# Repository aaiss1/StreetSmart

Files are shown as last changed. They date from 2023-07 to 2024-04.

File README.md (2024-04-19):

# StreetSmart

A bicycle safety device designed and built by 4 senior computer engineering students.

## Installing the Neopixel Library
```
sudo pip3 install rpi_ws281x adafruit-circuitpython-neopixel
sudo python3 -m pip install --force-reinstall adafruit-blinka
sudo apt-get install python-dev python3-dev -y
sudo pip3 install --upgrade RPi.GPIO
```

## Installing the RF24 Library
```
mkdir ~/rf24libs
cd ~/rf24libs
git clone https://github.com/TMRh20/RF24
cd ~/rf24libs/RF24
./configure
sudo make install
#Choose the SPIDEV Option
sudo apt-get install python3-dev libboost-python-dev
#Use ldconfig -p | grep libboost_python to find the number after libboost_python
sudo ln -s $(ls /usr/lib/arm-linux-gnueabihf/libboost_python3*.so | tail -1) /usr/lib/arm-linux-gnueabihf/libboost_python3.so
sudo apt-get install python3-setuptools
cd pyRF24/
sudo python3 setup.py build
sudo python3 setup.py install
sudo apt-get install python3-dev python3-rpi.gpio
```
## Connections for NRF24L01
```
On the Raspberry Side, the COMM Connections are
CSN_PIN = 0  # connected to GPIO8// ITS THE RASPI's CE PIN #
CE_PIN = 17  # connected to GPIO17
```

## File Hierarchy
- global_vars.py
    - main.py
        - lighting.py
        - comm.py     
        - accel.py    
        - lidar_dist.py          

## StreetSmart Service
### How to Run streetsmart on startup
```
sudo cp streetSmart.service /etc/systemd/system/
sudo systemctl daemon-reload
sudo systemctl enable streetSmart.service # Requires Reboot
#OR
sudo systemctl enable streetSmart.service --now #Runs as soon as called
```
### How to Stop streetsmart from running on startup
```
sudo systemctl disable streetSmart.service
```

### How to stop streetsmart when it is already running on startup
```
sudo systemctl stop streetSmart.service
```

## How to Run StreetSmart Manually

```
sudo python3 main.py

#CTRL C to kill
```

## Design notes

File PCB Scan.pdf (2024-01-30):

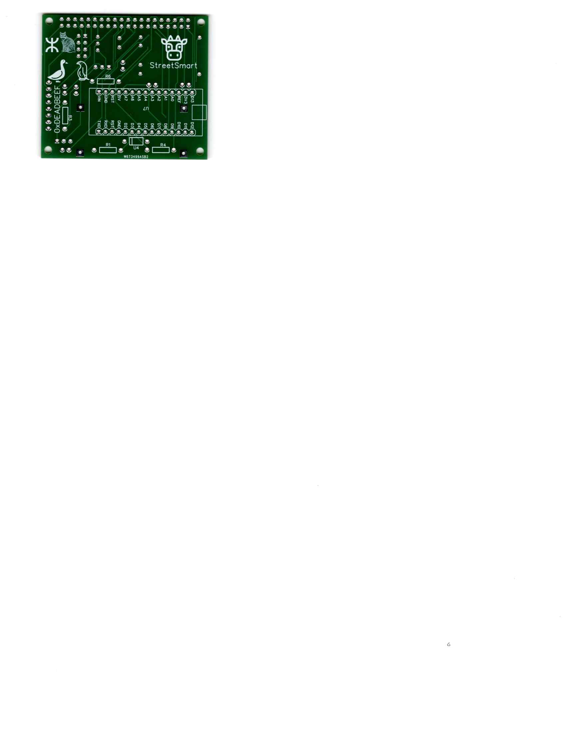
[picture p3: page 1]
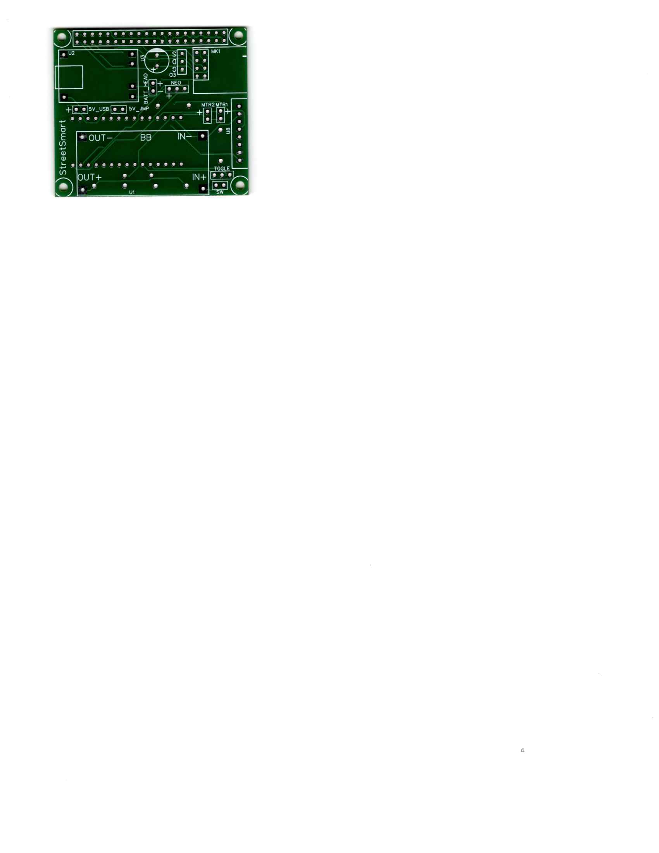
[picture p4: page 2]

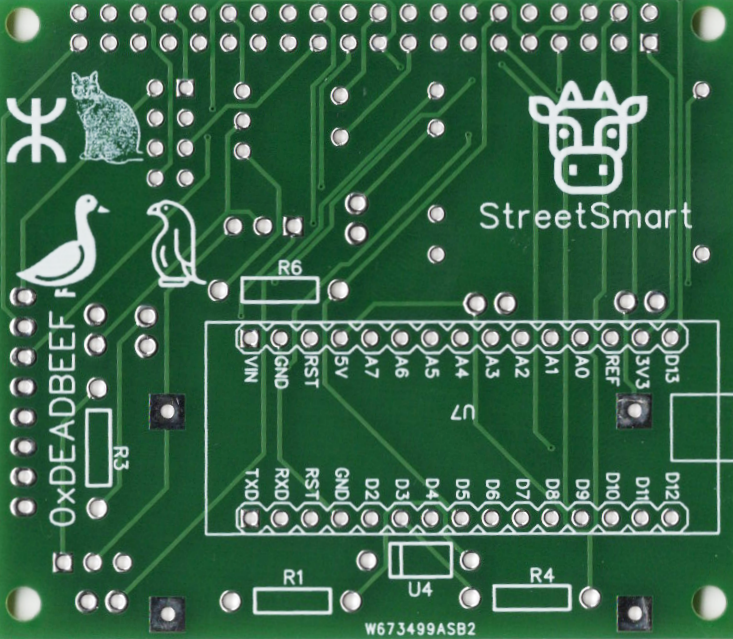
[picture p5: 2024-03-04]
PCB Scan _Cow.png

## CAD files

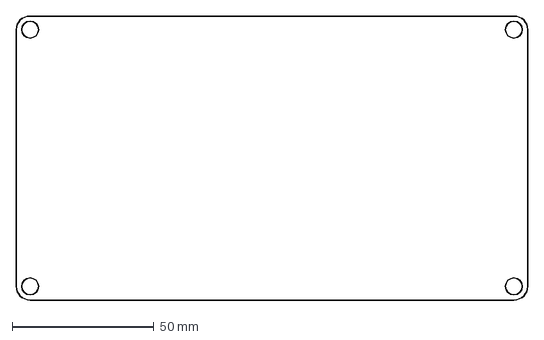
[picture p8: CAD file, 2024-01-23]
3D - Version 2/Acrylic Cover.dxf
180.0 x 100.0 mm

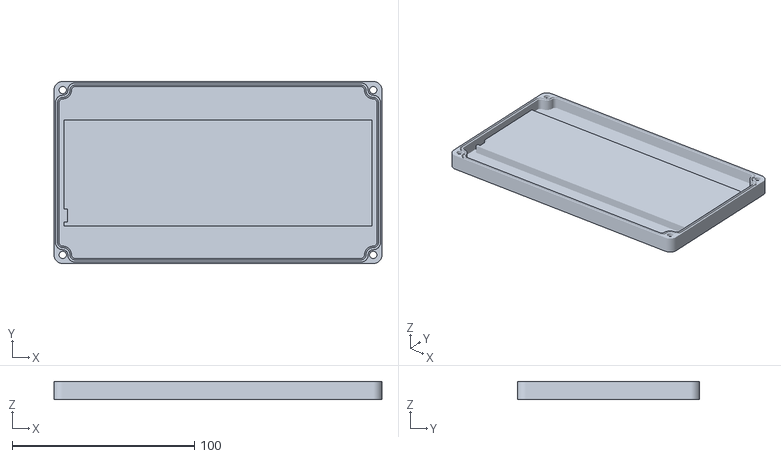
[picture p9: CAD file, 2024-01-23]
3D - Version 2/To Print 2024-01-21/Central-lid_2024_01_21.stl
180.0 x 100.0 x 10.0

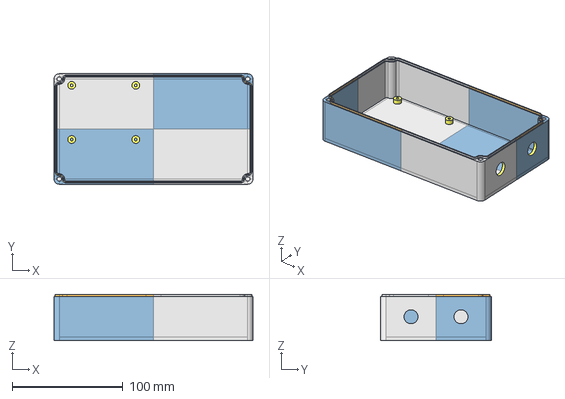
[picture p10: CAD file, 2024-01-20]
3D - Version 2/Central-base.step
180.0 x 100.0 x 41.7 mm

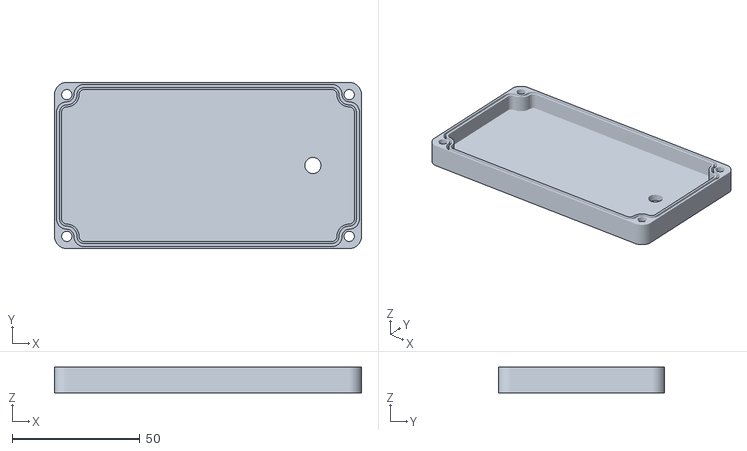
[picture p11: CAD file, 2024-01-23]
3D - Version 2/To Print 2024-01-21/Haptic Controller-lid v1.stl
120.0 x 65.0 x 10.0

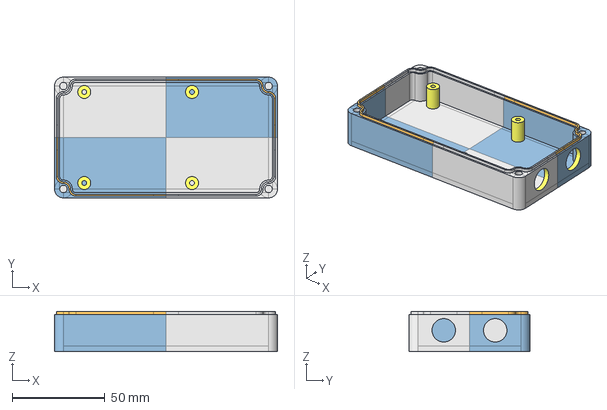
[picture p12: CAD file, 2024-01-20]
3D - Version 2/Haptic Controller-base.step
120.0 x 65.0 x 21.7 mm

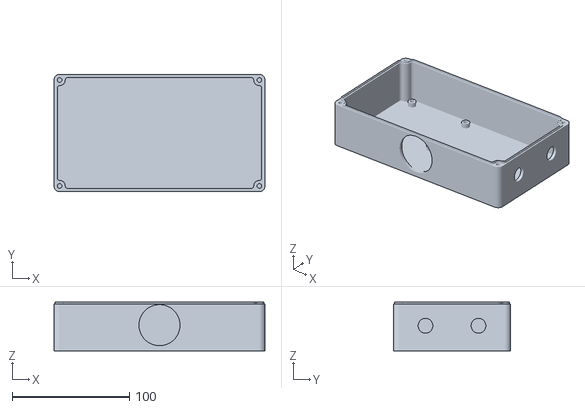
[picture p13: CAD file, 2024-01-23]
3D - Version 2/To Print 2024-01-21/Central-base v3.stl
180.0 x 100.0 x 41.7

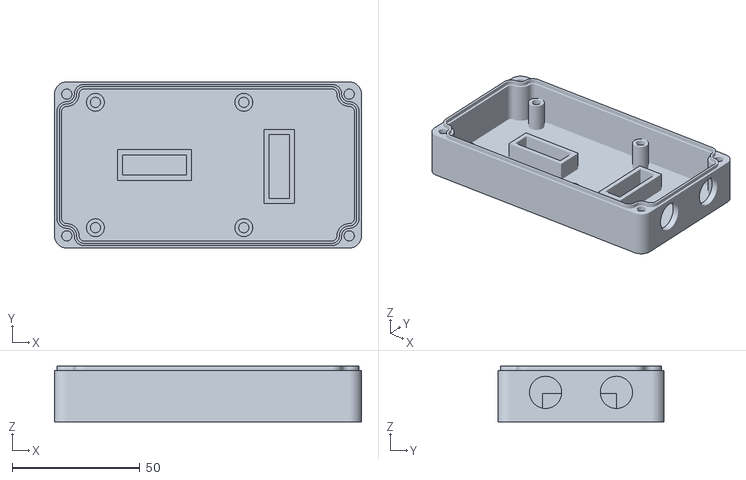
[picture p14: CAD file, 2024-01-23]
3D - Version 2/To Print 2024-01-21/Haptic Controller-base v2.stl
120.0 x 65.0 x 21.7

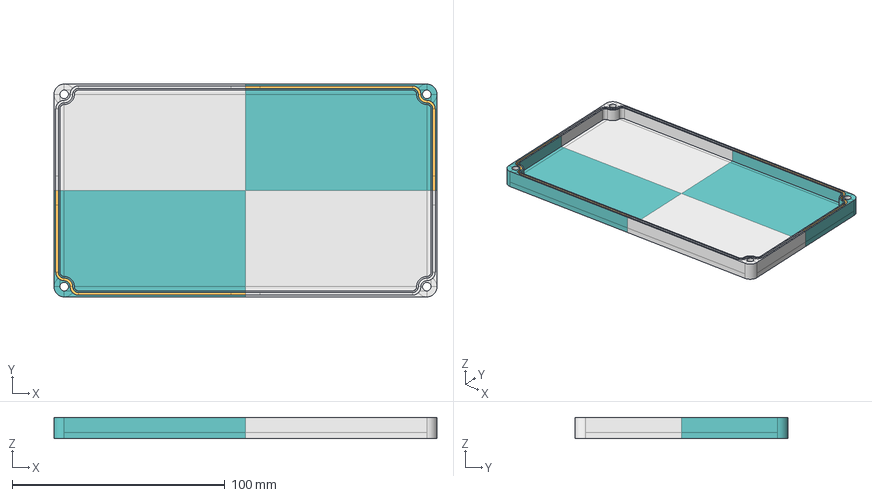
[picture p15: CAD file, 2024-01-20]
3D - Version 2/Central-lid.step
180.0 x 100.0 x 10.0 mm

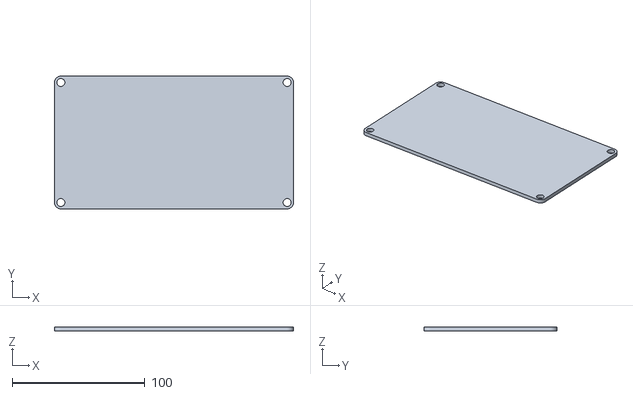
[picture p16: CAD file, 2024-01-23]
3D - Version 2/To Print 2024-01-21/clear_cover.stl
180.0 x 100.0 x 3.00

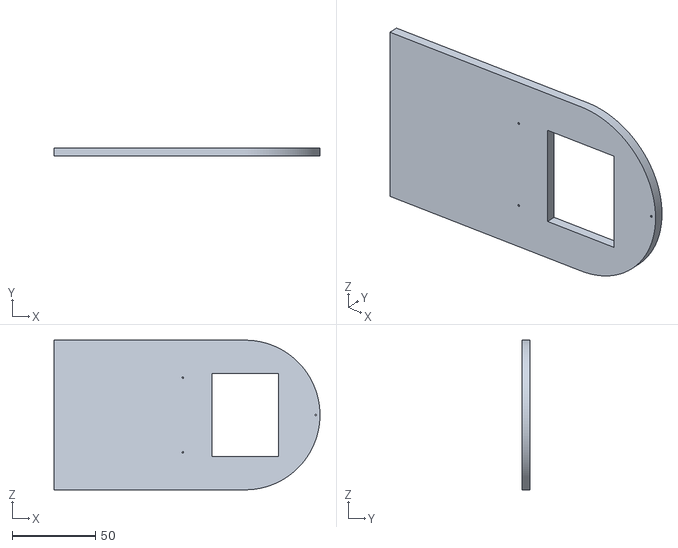
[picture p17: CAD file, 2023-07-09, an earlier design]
3D - Version 1/Central/right_front_plate.stl
160.0 x 5.00 x 90.0

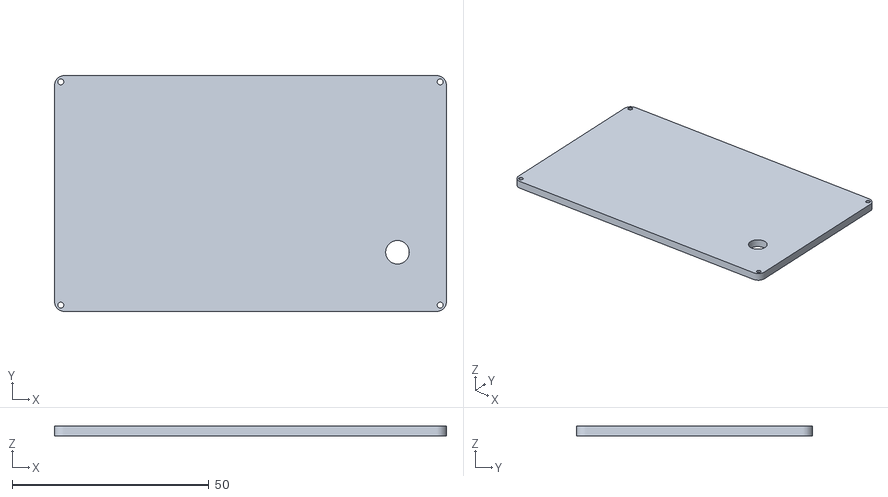
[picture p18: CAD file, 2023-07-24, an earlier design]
3D - Version 1/Haptic/wireless_lid2.stl
99.7 x 60.0 x 2.50

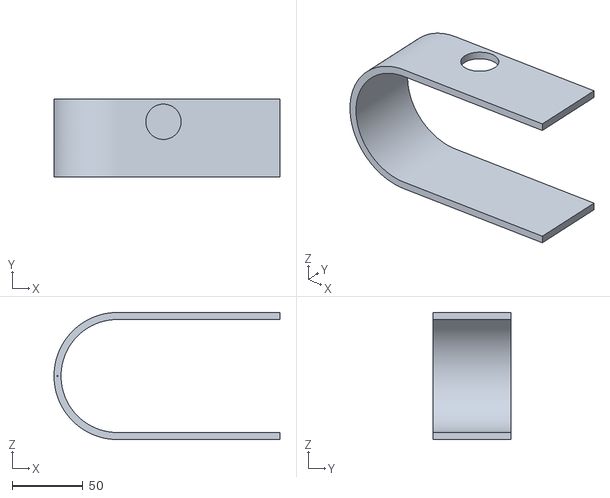
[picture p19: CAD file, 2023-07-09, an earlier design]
3D - Version 1/Central/left_body.stl
160.0 x 55.0 x 90.0

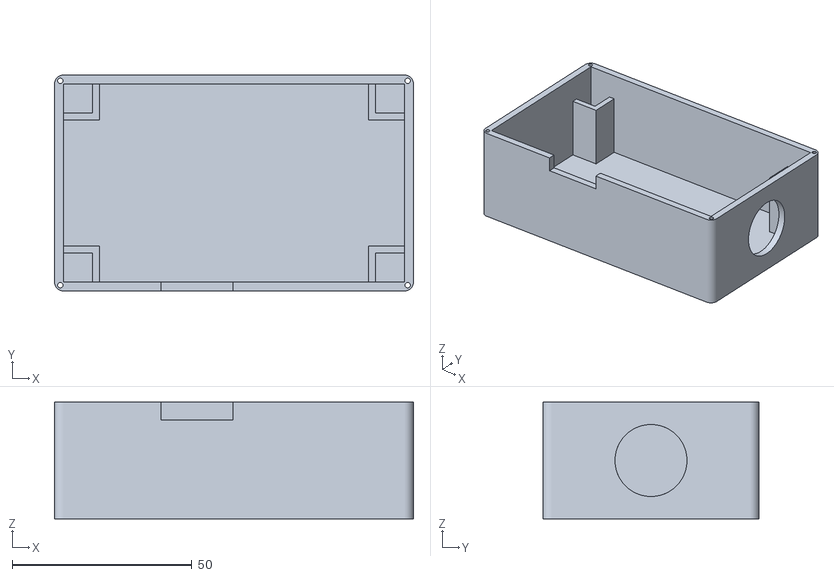
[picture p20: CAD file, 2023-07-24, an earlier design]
3D - Version 1/Haptic/wireless_container.stl
99.7 x 60.0 x 32.5

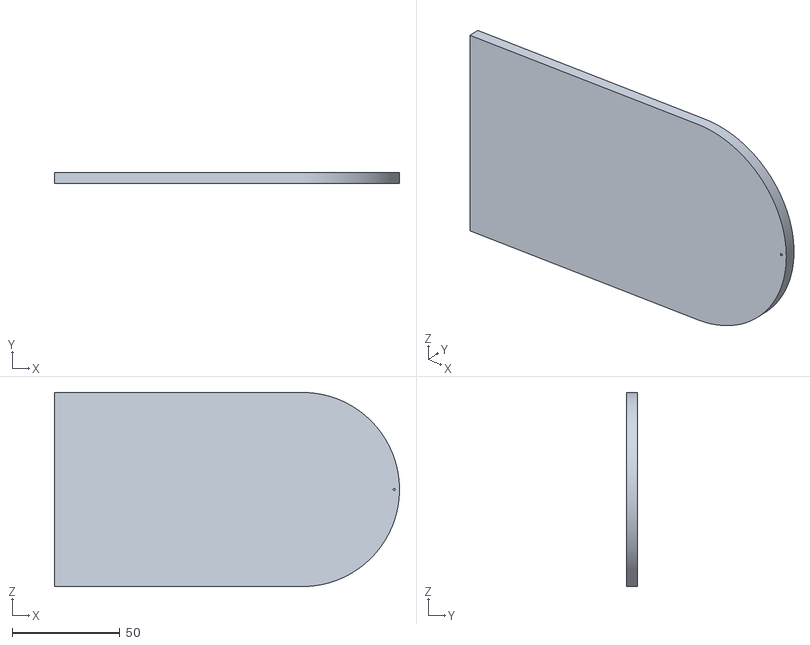
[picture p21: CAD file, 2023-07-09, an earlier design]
3D - Version 1/Central/right_back_plate.stl
160.0 x 5.00 x 90.0

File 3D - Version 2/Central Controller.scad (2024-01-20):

/*******************************************************************************
TITLE:
Stable and waterproof OpenSCAD case by pbtec

DESCRIPTION:

highly scalable case for 3D printing. Try it out!

Optimized for Openscad Customizer. Activate it under view/customizer and play around ;-)

No Support needed to print

- for waterproof cases you can use silicone sealing cord with diameters from 1 to 3mm
- to use also without sealing cord. The groove and ridge gives the housing a high stability and tightness.
- Use of regular nuts or square nuts
- define outer vertical radius of corners
- echo output in console shows inner and outer size and more
- echo output shows the needed length of the screws
- use screws from m2 up to m5
- default are 4 screws at each corner. For large cases add addtional ones in the middle of both x and y sides if needed
- use several predefined wall mount holder, some with multiple mounting holes (up to 3)

Important!
- If you use standard nuts you need to pause the printer a certain level to insert the nuts
- If you need a stable and waterproof case please print with 100% infill
- I'm aware that sometimes, when using too big or too small parameters, there are some rendering issues.
  To prevent such issues change only one parameter at once and check the result.

for waterproofness see https://blog.prusaprinters.org/watertight-3d-printing-part-2_53638/

AUTHOR:
pbtec / pb-tec.ch

use https://paypal.me/pbtec if you want to spend me a coold beer. Thanks in advance :-)


VERSION:
V   KZZ DATE     COMMENT
6.0 pb  31.07.21 First Version to share

*******************************************************************************/

/* [View settings] */
// Shows the Bottom of the case
ShowBottom                = true;
// Shows the top of the case
ShowTop                   = true;
// Distance between top and bottom (if both are side by side displayed)
DistanceBetweenObjects    = 10;
// Shows the housing assembled
ShowCaseAssembled         = false;


/* [Control cuts (use only one at a time)] */

// To see the nuts inside (best view if not assembled showed)
SeeNutCut                 = false;
// To see the groove, ridge and Screw (best view if assembled showed)
SeeGrooveRidgeScrew       = false;


/* [Case settings] */

// Length of the case
Caselength                = 60;
// Width of the case
CaseWidth                 = 80;
// Height of the case
CaseHeight                = 40;
// Splitt the Case height into bottom and top, check for the needed screws in echo output (console)
CutFromTop                = 10.0;    
// Thickness for the bottom and top wall (vertical walls needs to be calculated)
BottomTopThickness        = 3.0; 
// If this is bigger than the needed cylinder around the screw it will be ignored
CaseRadius                = 12.0;     

/* [Case Screw settings] */

//2=m2/2.5=m2.5/3=m3/4=m4/5=m5   // max m5, larger sizes do not fit
CountersinkScrew          = 3.0;     // [2:m2, 2.5: m2.5, 3: m3, 4: m4, 5: m5]

// Adds additional Screws on X axis (for large cases) --> Try it out
XAdditionalScrew          = false;  // can be true or false / Adds additional Screws on X axis (for large cases) --> Try it out
// Adds additional Screws on Y axis (for large cases) --> Try it out
YAdditionalScrew          = false;  // can be true or false / Adds additional Screws on Y axis (for large cases) --> Try it out

/* [Groove settings] */

// If using a SealingCord use the SealingCord diameter, otherwise x-times of your 3D Printer Nozzle (0.8/1.2/...) --> Ridge gets perfect for printing
GrooveWidth               = 1.2;   // [0.8:0.1:3]

// Not less than 1mm (for stability) and not more than 3mm --> Best 2mm
GrooveDepth               = 2.0;   // [1.0:0.1:3]

// Space between Groove and Ridge for a perfect fit, usualy 0.2 or 0.3 for FDM depending on your printer quality
Space                     = 0.3;   // [0.0:0.1:0.4]

// Addtional vertical room for the pressed sealing Cord. For sealing cord 1.5mm -->0.5 // for 2mm -->0.8 // for 2.5 -->1.0 // If no sealing cord then set this parameter to 0.
AddGrooveDepthForSealing  = 0.8;   // [0.0:0.1:3]   

// Range Inside groove/ridge. Usualy 2 times or more the printer nozzle. For best stability at least 0.8
InnerBorder               = 0.8;   // [0.8:0.1:4]


// Range Outside groove/ridge . Usualy 2 times or more the printer nozzle. For best stability at least 0.8
OuterBorder               = 0.8;   // [0.8:0.1:4]

/* [Nut general settings] */

// Size of material (plastic) above nut/square nut (3mm or more). The more, the more stable but need longer screw.
NutSink                   = 4.0; 

/* [Standard nut settings] */

// Nut Settings / As there are (or I have) many different nuts dimensions, the size must be specified / Do not add separation space, only the real measurement // m2=1.5 // m2.5=1.9 // m3=2.4 // m4=3.2 // n5=3.8
NutHigh                   = 2.4;   

// Distance between the paralell sides / Do not add separation space, only the real measurement // m2=3.8 // m2.5=4.9 // m3=5.4 // m4=6.9 // m5=7.9
NutDia                    = 5.4;   

/* [Square Nut settings] */

// Select if you want to use square nuts instead of normal nuts
UseSquareNutInsteadOfNut  = false; 

// Select the high of the square nut / Do not add separation space, only the real measurement
SquareNutHigh             = 1.9;

// Select the size of the square nut / Do not add separation space, only the real measurement
SquareNutSize             = 5.4;

// Square nut insert from which side
EdgeSquareNutInsertFrom_X = true;       

/* [Wall mount holder settings] */
 
// Select if you need a mount holder
EnableMountHolder         = false; 

// Chose your desired wall mount style
MountHolderStyle          = 5;      // [1:Style 1, 2: Style 2, 3: Style 3, 4 : Style 4, 5 : Style 5]

// Some styles (1-3) allow more than one hole
CountOfMountHolderHoles   = 1;     // [1:One hole centered, 2: Two holes, 3: Three holes]
MountHolderHoleDiameter   = 5;   // [1:0.1:10]
MountHolderThickness      = 4.0;   // [2:0.1:10]

/* [PCB/Device holder settings] */
// Activate customizable PCB/Device holder
ShowDeviceHolder         = false;
// Hole in the cylinder for the screw // 2.9 Screw = 2mm hole
ScrewHoleDiameter        = 2.6;  
// The diamter of the screw cylinder
ScrewCylinderDiameter    = 7;
// The height of the screw cylinders (also the deepness for the screw hole)
ScrewCylinderHeight      = 8.0;
// Distance between the holders in X direction
DeviceHolder_X_Distance  = 60;
// Distance between the holders in Y direction
DeviceHolder_y_Distance  = 80;
// Move all holders in X direction
Offset_X                 = 0;
// Move all holders in Y direction
Offset_Y                 = -20;

/* [Wall Holes settings (for cable gland cut)] */
// Activate customizable holes for cable gland or similar
ShowSideWallHoles        = false;
// Holes on X or Y side of the housing
SideWallHolesOn_X        = false;
// Count of holes, if there is an additional screw on X or Y side the hole in the middle is not showed
CountOfSideWallHoles     = 1;     //[1:1:3]
// Diameter of the holes
SideWallHoleDiameter     = 16.5;  //[1:0.1:80]
// Add or decrease height position
SiedWallHoleOffset_Z     = 0;     



/* [Render quality settings] */
// Set to at least to 150 before render and save as .stl file, otherwise you can go down to 40 for quick 3D view
$fn                       = 60;   // [20:1:300] 

// =========================  C A L C U L A T E D   S E T T I N G S (do not change!!!) ===================================

// Calculated Screw settings (do not change!!!)
ScrewHoleDia              = CountersinkScrew+1;
ScrewHeadDia              = CountersinkScrew*2;
ScrewCountersink          = (CountersinkScrew+8)/14-0.5;

// Calculated settings for Ridge (do not change!!!)
RidgeHeight               = GrooveDepth-Space;
RidgeWidth                = GrooveWidth-Space;

// Calculated settings for case (do not change!!!)
SideWallThickness             = InnerBorder+GrooveWidth+OuterBorder;
CaseRoundingRadius        = ScrewHoleDia/2+InnerBorder+GrooveWidth+OuterBorder;
ScrewCornerPos            = [Caselength/2-CaseRoundingRadius,CaseWidth/2-CaseRoundingRadius,0];
ScrewAddXPos              = [0,CaseWidth/2-CaseRoundingRadius,0];
ScrewAddYPos              = [Caselength/2-CaseRoundingRadius,0,0];

// Calculated settings for wall mount holder
MountHolderLenght         = MountHolderHoleDiameter*3;

// if both objects showed
X_ObjectPosition = ((ShowBottom)&&(ShowTop)&&(!ShowCaseAssembled)) ? Caselength/2+DistanceBetweenObjects/2:0;

// If the case is assembled showed
Y_TopRotation = ShowCaseAssembled ? 180:0;
Z_TopHigh = ShowCaseAssembled ? CaseHeight:0;

ShowSizes(); // Show the calculated sizes

//===============================================================================
//                                    M A I N
//===============================================================================
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

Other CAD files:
3D - Version 2/Haptic Controller-lid.step
3D - Version 1/Central/left_back_plate.stl
3D - Version 1/Central/left_front_plate.stl
3D - Version 1/Central/right_body.stl
3D - Version 1/Central/light_panel.stl
3D - Version 2/Central-lid v5.f3d
3D - Version 2/Central-lid_v5_v1.f3d

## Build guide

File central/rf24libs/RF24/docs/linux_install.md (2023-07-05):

# Linux Installation

@tableofcontents

<!-- markdownlint-disable MD031 -->
Generic Linux devices are supported via SPIDEV, MRAA, RPi native via BCM2835, or using LittleWire.

@note The SPIDEV option should work with most Linux systems supporting spi userspace device.

@warning These install instructions are beginning to age because they were designed with the assumption that
the arm-linux-gnueabihf-g\*\* compilers were available and default for the system. If you have problems
using the manual install instructions (especially on a 64-bit OS), please try the
[instructions using CMake](md_docs_using_cmake.html).

@note Since wiringPi is no longer maintained or distributed (as of RPi OS 11 bullseye),
pigpio is now required for using the radio's IRQ pin. This applies to RPi, SPIDEV, and pigpio drivers. The MRAA driver may provide its own IRQ implementation. Remember that the RPi OS lite variant does not ship with pigpio installed.

## Automated Install

**Designed & Tested on RPi** - Defaults to SPIDEV on devices supporting it

1. Install prerequisites if there are any (pigpio, MRAA, LittleWire libraries, setup SPI device etc)
2. Download the install.sh file from [http://tmrh20.github.io/RF24Installer/RPi/install.sh](http://tmrh20.github.io/RF24Installer/RPi/install.sh)
   ```shell
   wget http://tmrh20.github.io/RF24Installer/RPi/install.sh
   ```
3. Make it executable
   ```shell
   chmod +x install.sh
   ```
4. Run it and choose your options
   ```shell
   ./install.sh
   ```
5. Run an example from one of the libraries
   ```shell
   cd rf24libs/RF24/examples_linux
   ```
   Edit the gettingstarted example, to set your pin configuration
   ```shell
   nano gettingstarted.cpp
   make
   sudo ./gettingstarted
   ```

## Manual Install

1. Install prerequisites if there are any (pigpio, MRAA, LittleWire libraries, setup SPI device etc)
   @note See the [MRAA](http://iotdk.intel.com/docs/master/mraa/index.html) documentation for more info on installing MRAA
2. Make a directory to contain the RF24 and possibly RF24Network lib and enter it
   ```shell
   mkdir ~/rf24libs
   cd ~/rf24libs
   ```
3. Clone the RF24 repo
   ```shell
   git clone https://github.com/tmrh20/RF24.git RF24
   ```
4. Change to the new RF24 directory
   ```shell
   cd RF24
   ```
5. Configure build environment using
   ```shell
   ./configure
   ```
   script. It auto detectes device and build environment.

   For overriding autodetections, use command-line switches, see
   ```shell
   ./configure --help
   ```
   for description.
6. Build the library, and run an example file
   ```shell
   make
   sudo make install
   ```
   ```shell
   cd examples_linux
   ```
   Edit the gettingstarted example, to set your pin configuration
   ```shell
   ano gettingstarted.cpp
   make
   sudo ./gettingstarted
   ```

### Build using SPIDEV

1. Make sure that spi device support is enabled and /dev/spidev\<a\>.\<b\> is present
2. Manual Install using SPIDEV:
   ```shell
   ./configure --driver=SPIDEV
   make
   sudo make install
   ```
3. See the gettingstarted example for an example of pin configuration

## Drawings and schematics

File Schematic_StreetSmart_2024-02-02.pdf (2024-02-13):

## Output is 5V for Central Output is 6V for Haptic

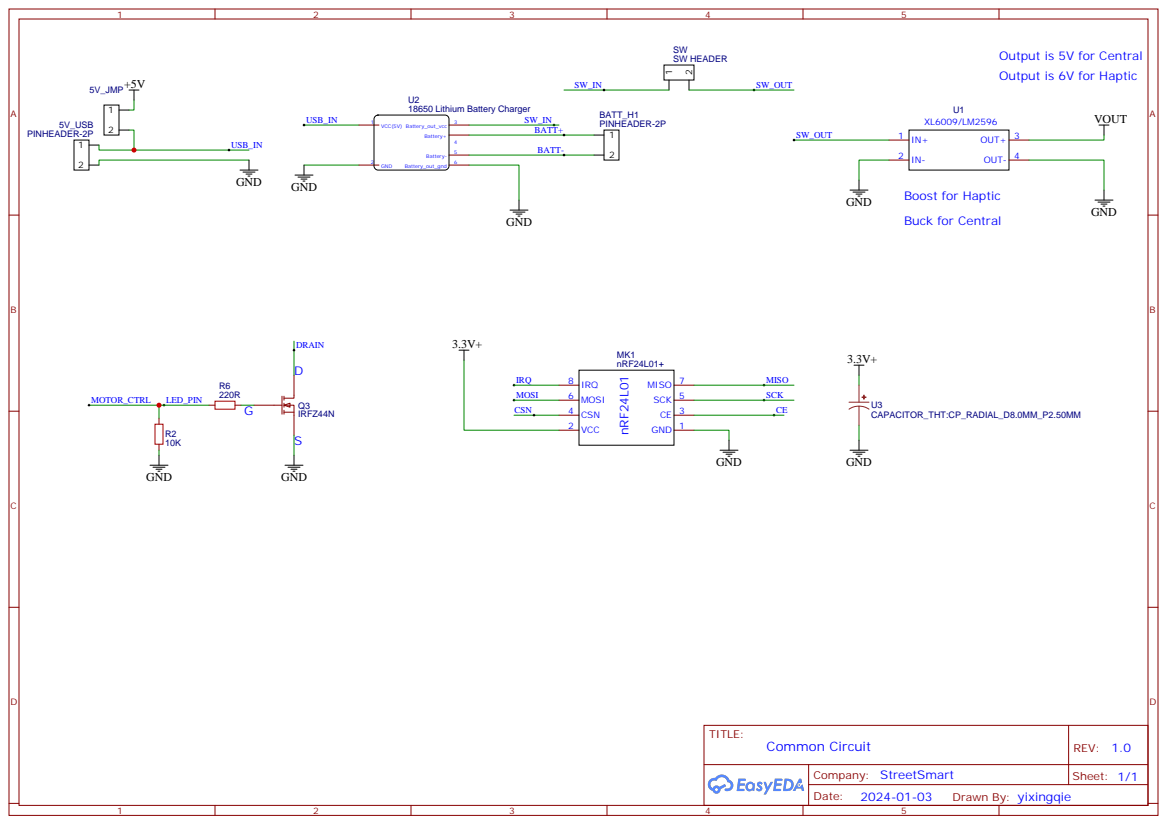
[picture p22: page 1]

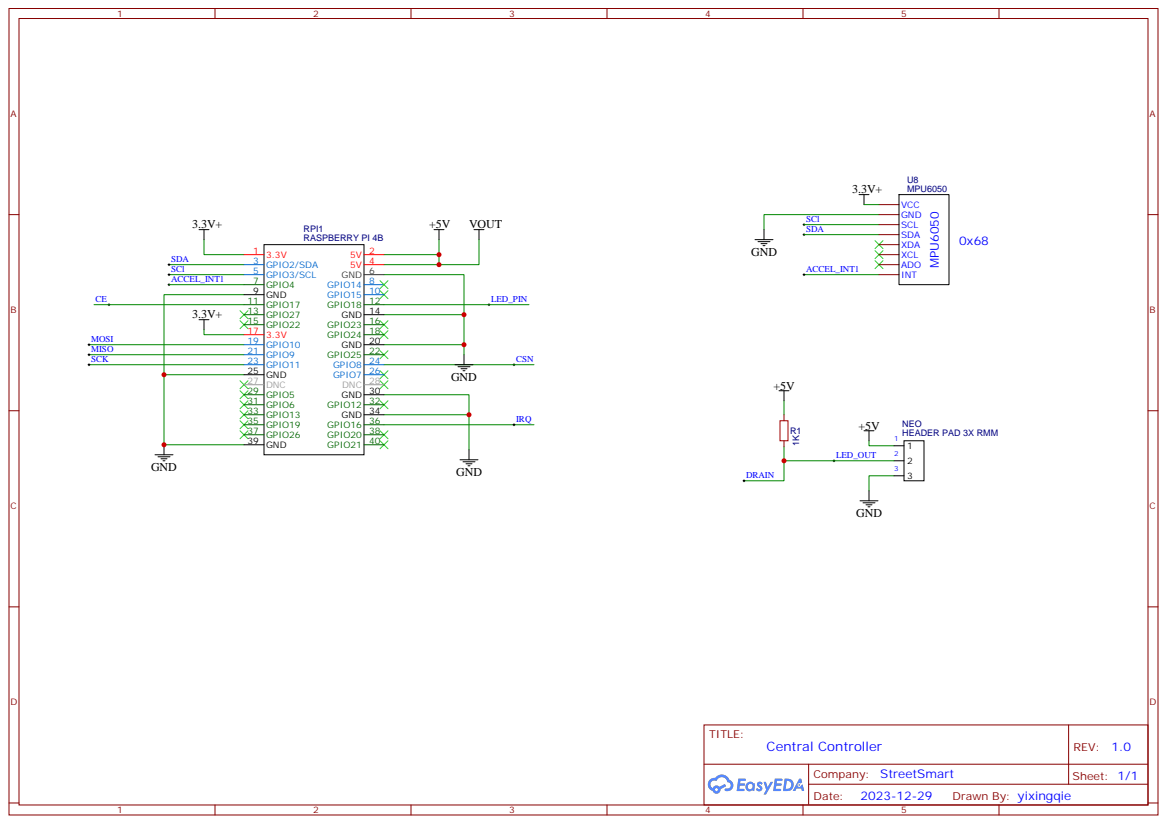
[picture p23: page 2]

## MOTOR+ MOTOR- DRAIN

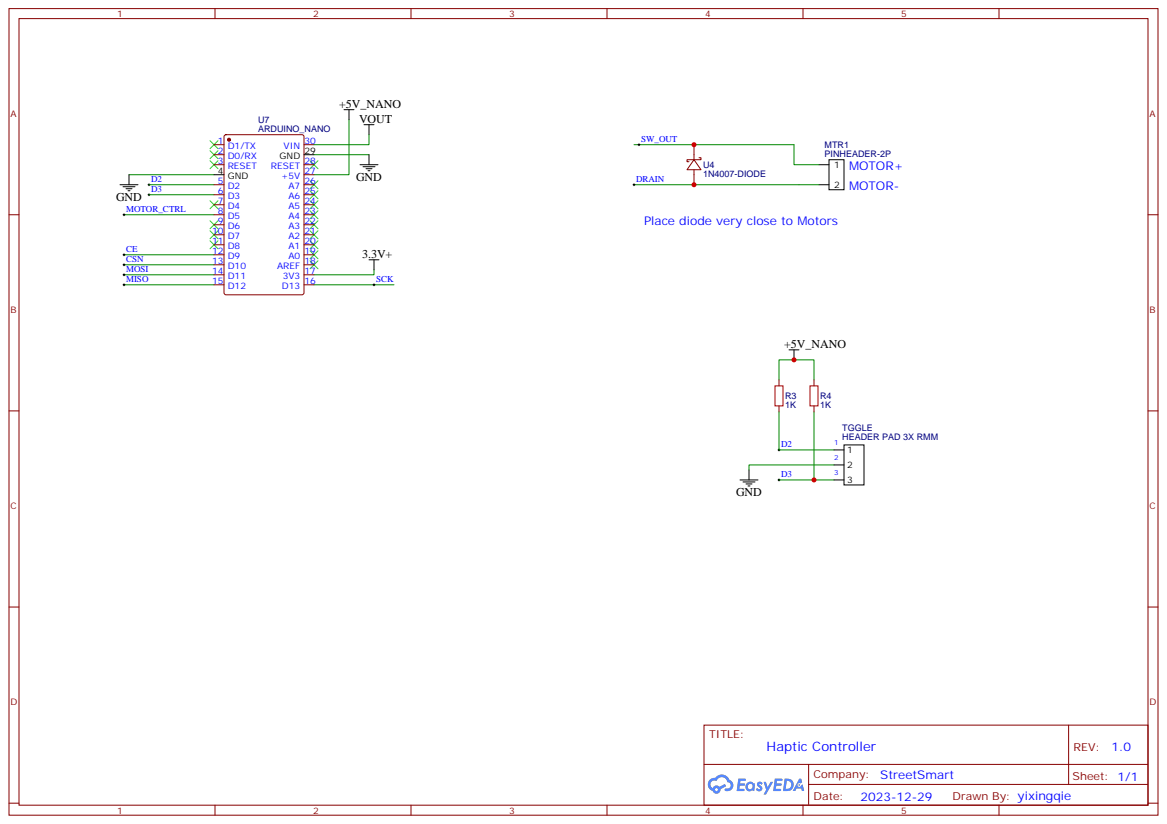
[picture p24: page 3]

Place diode very close to Motors

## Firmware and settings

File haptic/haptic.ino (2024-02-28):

#include <SPI.h>
#include "printf.h"
#include "RF24.h"
#include <stdbool.h>

const int LEFT_SIG = 2;
const int RIGHT_SIG = 3;
const int LEFT_LED = 7;
const int RIGHT_LED = 6;
const int MODE_LED = 4;

const int MODE_BUTTON = A0;

const int MOTOR_CTRL = 5;

volatile int turn = 0;
// 0  = do nothing
// 1 = turn left
// -1 = turn right

volatile int haptic = 0;
// 0  = do nothing
// 1 = vibrate
const long turn_led_blink_time = 750;
const long status_led_blink_time = 500;
const long haptic_off_blink_time = 2000;
const int timeout_time = 3000;
long vibration_time = 200;

int turn_led_state = LOW;  // ledState used to set the LED
int status_led_state = LOW;  // ledState used to set the LED

// 0 - haptic on (normal)
// 1 - haptic off
bool is_haptic_on = true;
bool in_adjust_mode = false;
bool is_connected = false;

// Generally, you should use "unsigned long" for variables that hold time
// The value will quickly become too large for an int to store
unsigned long turn_led_prev_time = 0;  // will store last time LED was updated
unsigned long status_led_prev_time = 0;  // will store last time LED was updated
unsigned long last_connected_time = 0;

int haptic_drive = 0;
int signal_counter = 0;

uint8_t distance_mode = 0;

// These are used for interrupt button handling
long debouncing_time = 300; // Debouncing Time in Milliseconds
volatile unsigned long last_micros;
volatile unsigned long last_vib_micros;

/**
 * A simple example of sending data from 1 nRF24L01 transceiver to another
 * with Acknowledgement (ACK) payloads attached to ACK packets.
 *
 * This example was written to be used on 2 devices acting as "nodes".
 * Use the Serial Monitor to change each node's behavior.
 */

#define CE_PIN 9
#define CSN_PIN 10
// instantiate an object for the nRF24L01 transceiver
RF24 radio(CE_PIN, CSN_PIN);

// an identifying device destination
// Let these addresses be used for the pair
uint8_t address[][6] = {"1Node", "2Node"};
// It is very helpful to think of an address as a path instead of as
// an identifying device destination
// to use different addresses on a pair of radios, we need a variable to

// uniquely identify which address this radio will use to transmit
bool radioNumber = 1; // 0 uses address[0] to transmit, 1 uses address[1] to transmit

// Used to control whether this node is sending or receiving
bool role = false; // true = TX role, false = RX role

// For this example, we'll be using a payload containing
// a string & an integer number that will be incremented
// on every successful transmission.
// Make a data structure to store the entire payload of different datatypes
struct PayloadStruct
{
  // char message[9];
  uint8_t stat;
  uint8_t distance_mode;
};
PayloadStruct payload;

// https://forum.arduino.cc/t/adding-a-double-click-case-statement/283504/3
/*
To keep a physical interface as simple as possible, this sketch demonstrates generating four output events from a single push-button.
1) Click:  rapid press and release
2) Double-Click:  two clicks in quick succession
3) Press and Hold:  holding the button down
4) Long Press and Hold:  holding the button for a long time 
*/
// Button timing variables
int debounce = 5;          // ms debounce period to prevent flickering when pressing or releasing the button
int DCgap = 500;            // max ms between clicks for a double click event
int holdTime = 2000;        // ms hold period: how long to wait for press+hold event
int longHoldTime = 4000;    // ms long hold period: how long to wait for press+hold event

// Button variables
bool buttonVal = HIGH;   // value read from button
bool buttonLast = HIGH;  // buffered value of the button's previous state
bool DCwaiting = false;  // whether we're waiting for a double click (down)
bool DConUp = false;     // whether to register a double click on next release, or whether to wait and click
bool singleOK = true;    // whether it's OK to do a single click
long downTime = -1;         // time the button was pressed down
long upTime = -1;           // time the button was released
bool ignoreUp = false;   // whether to ignore the button release because the click+hold was triggered
bool waitForUp = false;        // when held, whether to wait for the up event
bool holdEventPast = false;    // whether or not the hold event happened already
bool longHoldEventPast = false;// whether or not the long hold event happened already

int check_mode_button() {    
   int event = 0;
   // poll button - range 655-0, 500 arbitrary toggle value
   buttonVal = analogRead(MODE_BUTTON) < 500? LOW : HIGH;
   // Button pressed down
   if (buttonVal == LOW && buttonLast == HIGH && (millis() - upTime) > debounce)
   {
       downTime = millis();
       ignoreUp = false;
       waitForUp = false;
       singleOK = true;
       holdEventPast = false;
       longHoldEventPast = false;
       if ((millis()-upTime) < DCgap && DConUp == false && DCwaiting == true)  DConUp = true;
       else  DConUp = false;
       DCwaiting = false;
   }
   // Button released
   else if (buttonVal == HIGH && buttonLast == LOW && (millis() - downTime) > debounce)
   {        
       if (!ignoreUp)
       {
           upTime = millis();
           if (DConUp == false) DCwaiting = true;
           else
           {
               event = 2;
               DConUp = false;
               DCwaiting = false;
               singleOK = false;
           }
       }
   }
   // Test for normal click event: DCgap expired
   if ( buttonVal == HIGH && (millis()-upTime) >= DCgap && DCwaiting == true && DConUp == false && singleOK == true && event != 2)
   {
       event = 1;
       DCwaiting = false;
   }
   // Test for hold
   if (buttonVal == LOW && (millis() - downTime) >= holdTime) {
       // Trigger "normal" hold
       if (!holdEventPast)
       {
           event = 3;
           waitForUp = true;
           ignoreUp = true;
           DConUp = false;
           DCwaiting = false;
           //downTime = millis();
           holdEventPast = true;
       }
       // Trigger "long" hold
       if ((millis() - downTime) >= longHoldTime)
       {
           if (!longHoldEventPast)
           {
               event = 4;
               longHoldEventPast = true;
           }
       }
   }
   buttonLast = buttonVal;
   return event;
}


void setup()
{
  // pinMode(LEFT_SIG, INPUT_PULLUP);  // sets all button interrupts as pull ups
  // pinMode(RIGHT_SIG, INPUT_PULLUP); // sets all button interrupts as pull ups

  pinMode(MOTOR_CTRL, OUTPUT); // sets all button interrupts as pull ups
  digitalWrite(MOTOR_CTRL, 0);

  pinMode(LEFT_LED, OUTPUT); // sets all button interrupts as pull ups
  digitalWrite(LEFT_LED, 0);
  pinMode(RIGHT_LED, OUTPUT); // sets all button interrupts as pull ups
  digitalWrite(RIGHT_LED, 0);

  pinMode(MODE_LED, OUTPUT); // led for connecting state
  digitalWrite(MODE_LED, 0);

  // attach interrupts to pins
  attachInterrupt(digitalPinToInterrupt(LEFT_SIG), left_ISR, FALLING);
  attachInterrupt(digitalPinToInterrupt(RIGHT_SIG), right_ISR, FALLING);
  Serial.begin(115200);
  while (!Serial)
  {
    // some boards need to wait to ensure access to serial over USB
  }

  // initialize the transceiver on the SPI bus
  if (!radio.begin())
  {
    Serial.println(F("radio hardware is not responding!!"));
    while (1)
    {
      
      digitalWrite(LEFT_LED, HIGH);
      digitalWrite(RIGHT_LED, HIGH);
      delay(300);
      digitalWrite(LEFT_LED, LOW);
      digitalWrite(RIGHT_LED, LOW);
      delay(300);
    } // hold in infinite loop
  }

  radioNumber = 1;
  Serial.print(F("radioNumber = "));
  Serial.println((int)radioNumber);

  // Set the PA Level low to try preventing power supply related problems
  // because these examples are likely run with nodes in close proximity to
  // each other.
  radio.setPALevel(RF24_PA_HIGH); // RF24_PA_MAX is default.
  radio.setChannel(127);
  radio.setDataRate(RF24_250KBPS);

  // to use ACK payloads, we need to enable dynamic payload lengths (for all nodes)
  radio.setPayloadSize(2);
  // Acknowledgement packets have no payloads by default. We need to enable
  // this feature for all nodes (TX & RX) to use ACK payloads.
  radio.enableAckPayload();

  // set the TX address of the RX node into the TX pipe
  radio.openWritingPipe(address[radioNumber]); // always uses pipe 0

  // set the RX address of the TX node into a RX pipe
  radio.openReadingPipe(1, address[!radioNumber]); // using pipe 1

  // memcpy(payload.message, "Turn: ", 6); // set the payload message
  // load the payload for the first received transmission on pipe 0
  payload.distance_mode = 0,
  payload.stat = 0,
  
  radio.writeAckPayload(1, &payload, sizeof(payload));

  radio.startListening(); // put radio in RX mode

  // For debugging info
  // printf_begin();             // needed only once for printing details
  // radio.printDetails();       // (smaller) function that prints raw register values
  // radio.printPrettyDetails(); // (larger) function that prints human readable data

  // in setup, check if button is held, if it is, toggle haptic off
  int button_status = analogRead(MODE_BUTTON) < 500? LOW : HIGH;
  if (button_status == LOW) {
    is_haptic_on = false;
  }
}


void flash_led(const int led_num, int *led_state, unsigned long* prev_time, int blink_time) {
  if ((long)(millis() - *prev_time >= blink_time)) {
    *prev_time = millis();

    *led_state = (*led_state == LOW)? HIGH : LOW;

    digitalWrite(led_num, *led_state);
  }
}

void loop()
{
  // poll button - range 655-0, 500 arbitrary toggle value
  if (is_connected) {
    int button_status = check_mode_button();
    if (button_status == 3) {
            Serial.println("2s HOLD!!\n\n");
      in_adjust_mode = !in_adjust_mode;
      turn = 0;
    } 
  }

  if (in_adjust_mode) {
    if (turn == 1) {
      // left: decrease distance
      distance_mode -= (distance_mode > 0)? 1 : 0;
    } else if (turn == 2) {
      // right: increase distance
      distance_mode += (distance_mode < 4)? 1 : 0;
    }
    turn = 0;

    flash_led(MODE_LED, &status_led_state, &status_led_prev_time, 250);
  } else {

  // turn led check
  if (turn == 1) {
    flash_led(LEFT_LED, &turn_led_state, &turn_led_prev_time, turn_led_blink_time);
  } else if (turn == 2) {
    flash_led(RIGHT_LED, &turn_led_state, &turn_led_prev_time, turn_led_blink_time);
  } else {
    turn_led_state = LOW;
    digitalWrite(LEFT_LED, LOW);
    digitalWrite(RIGHT_LED, LOW);
  }

  // if it is connected to central controller (central controller always sends message)
  uint8_t pipe;
  if (radio.available(&pipe))
  {                                                // is there a payload? get the pipe number that recieved it
    // signal_counter += (signal_counter == 50)? 0 : 1;
    uint8_t bytes = radio.getDynamicPayloadSize(); // get the size of the payload
    PayloadStruct received;
    radio.read(&received, sizeof(received)); // get incoming payload
    // Serial.print(F("Received "));
    // Serial.print(bytes); // print the size of the payload
    // Serial.print(F(" bytes on pipe "));
    // Serial.print(pipe); // print the pipe number
    // Serial.print(F(": "));
    // Serial.print(received.message); // print incoming message
    // Serial.print(received.stat); // print incoming status
    haptic = received.stat;

    if(haptic && is_haptic_on){ //Drives the Haptic Motor if Haptic Enabled
      // Serial.print(F("  !!!Haptic Enabled!!!  "));

      if ((long)(micros() - last_vib_micros) >= vibration_time * 1000)
      {
        // digitalWrite(MOTOR_CTRL, haptic_drive);
        digitalWrite(MOTOR_CTRL, 1);
        delay(100);
        digitalWrite(MOTOR_CTRL, 0);
        
        haptic_drive = !haptic_drive;
        last_vib_micros = micros();
      }
    }

    //Load the Payload Acknowledgement
    Serial.print(distance_mode);
    payload.stat = turn;
    payload.distance_mode = distance_mode;
    // Serial.print(F(" Sent: "));
    // Serial.print(payload.message);   // print outgoing message
    // Serial.println(payload.stat); // print outgoing counter
    radio.writeAckPayload(1, &payload, sizeof(payload));

    // keep status led on
    if (is_haptic_on) {
      digitalWrite(MODE_LED, HIGH);
    } else {
      flash_led(MODE_LED, &status_led_state, &status_led_prev_time, haptic_off_blink_time);
    }

    // track connected time
    last_connected_time = millis();
    is_connected = true;

  } else{
    // signal_counter -= (signal_counter == 0)? 0 : 1;
    // if (signal_counter == 0) {
    //   digitalWrite(MOTOR_CTRL, 0);
    // }
    digitalWrite(MOTOR_CTRL, 0);

    // flash status led
    if ((long)(millis() - last_connected_time >= timeout_time)) { // disconnected
      is_connected = false;
      is_haptic_on = true;
      flash_led(MODE_LED, &status_led_state, &status_led_prev_time, status_led_blink_time);
    }
  }


  if (haptic) {
    // Serial.println("Vibrating!!!");
    // quick flash
    if (turn_led_state == LOW) {
      // Serial.println("light is low!")
      // int flash_state = LOW;
      digitalWrite(LEFT_LED, HIGH);
      digitalWrite(RIGHT_LED, HIGH);
      delay(100);
      digitalWrite(LEFT_LED, LOW);
      digitalWrite(RIGHT_LED, LOW);
      // flash_led(LEFT_LED, &flash_state, &turn_led_prev_time, turn_led_blink_time);
      // flash_led(RIGHT_LED, &turn_led_state, &turn_led_prev_time, turn_led_blink_time);
      delay(100);
    } else {
      // Serial.println("light is !")

    }
  }
  }

} // loop

void left_ISR()
{ // increments mode selection
  if ((long)(micros() - last_micros) >= debouncing_time * 1000)
  {
    turn = (turn == 0)? 1 : 0;
    last_micros = micros();
  }
}

void right_ISR()
{ // increments mode selection
  if ((long)(micros() - last_micros) >= debouncing_time * 1000)
  {
    // Serial.println("H");
    turn = (turn == 0)? 2 : 0;
    last_micros = micros();
  }
}

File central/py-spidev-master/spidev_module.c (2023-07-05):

/*
 * spidev_module.c - Python bindings for Linux SPI access through spidev
 * Copyright (C) 2009 Volker Thoms <unconnected@gmx.de>
 * Copyright (C) 2012 Stephen Caudle <scaudle@doceme.com>
 *
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
 * You should have received a copy of the GNU General Public License
 * along with this program; if not, write to the Free Software
 * Foundation, Inc., 59 Temple Place - Suite 330, Boston, MA  02111-1307, USA.
 */

#include <Python.h>
#include "structmember.h"
#include <stdlib.h>
#include <stdio.h>
#include <fcntl.h>
#include <linux/spi/spidev.h>
#include <linux/types.h>
#include <sys/ioctl.h>
#include <linux/ioctl.h>

#define _VERSION_ "3.3"
#define SPIDEV_MAXPATH 4096


#if PY_MAJOR_VERSION < 3
#define PyLong_AS_LONG(val) PyInt_AS_LONG(val)
#define PyLong_AsLong(val) PyInt_AsLong(val)
#endif

// Macros needed for Python 3
#ifndef PyInt_Check
#define PyInt_Check			PyLong_Check
#define PyInt_FromLong	PyLong_FromLong
#define PyInt_AsLong		PyLong_AsLong
#define PyInt_Type			PyLong_Type
#endif

PyDoc_STRVAR(SpiDev_module_doc,
	"This module defines an object type that allows SPI transactions\n"
	"on hosts running the Linux kernel. The host kernel must have SPI\n"
	"support and SPI device interface support.\n"
	"All of these can be either built-in to the kernel, or loaded from\n"
	"modules.\n"
	"\n"
	"Because the SPI device interface is opened R/W, users of this\n"
	"module usually must have root permissions.\n");

typedef struct {
	PyObject_HEAD

	int fd;	/* open file descriptor: /dev/spidevX.Y */
	uint8_t mode;	/* current SPI mode */
	uint8_t bits_per_word;	/* current SPI bits per word setting */
	uint32_t max_speed_hz;	/* current SPI max speed setting in Hz */
} SpiDevObject;

static PyObject *
SpiDev_new(PyTypeObject *type, PyObject *args, PyObject *kwds)
{
	SpiDevObject *self;
	if ((self = (SpiDevObject *)type->tp_alloc(type, 0)) == NULL)
		return NULL;

	self->fd = -1;
	self->mode = 0;
	self->bits_per_word = 0;
	self->max_speed_hz = 0;

	Py_INCREF(self);
	return (PyObject *)self;
}

PyDoc_STRVAR(SpiDev_close_doc,
	"close()\n\n"
	"Disconnects the object from the interface.\n");

static PyObject *
SpiDev_close(SpiDevObject *self)
{
	if ((self->fd != -1) && (close(self->fd) == -1)) {
		PyErr_SetFromErrno(PyExc_IOError);
		return NULL;
	}

	self->fd = -1;
	self->mode = 0;
	self->bits_per_word = 0;
	self->max_speed_hz = 0;

	Py_INCREF(Py_None);
	return Py_None;
}

static void
SpiDev_dealloc(SpiDevObject *self)
{
	PyObject *ref = SpiDev_close(self);
	Py_XDECREF(ref);

	Py_TYPE(self)->tp_free((PyObject *)self);
}

static char *wrmsg_list0 = "Empty argument list.";
static char *wrmsg_listmax = "Argument list size exceeds %d bytes.";
static char *wrmsg_val = "Non-Int/Long value in arguments: %x.";

PyDoc_STRVAR(SpiDev_write_doc,
	"write([values]) -> None\n\n"
	"Write bytes to SPI device.\n");

static PyObject *
SpiDev_writebytes(SpiDevObject *self, PyObject *args)
{
	int		status;
	uint16_t	ii, len;
	uint8_t	buf[SPIDEV_MAXPATH];
	PyObject	*obj;
	PyObject	*seq;
	char	wrmsg_text[4096];

	if (!PyArg_ParseTuple(args, "O:write", &obj))
		return NULL;

	seq = PySequence_Fast(obj, "expected a sequence");
	len = PySequence_Fast_GET_SIZE(seq);
	if (!seq || len <= 0) {
		PyErr_SetString(PyExc_TypeError, wrmsg_list0);
		return NULL;
	}

	if (len > SPIDEV_MAXPATH) {
		snprintf(wrmsg_text, sizeof (wrmsg_text) - 1, wrmsg_listmax, SPIDEV_MAXPATH);
		PyErr_SetString(PyExc_OverflowError, wrmsg_text);
		return NULL;
	}

	for (ii = 0; ii < len; ii++) {
		PyObject *val = PySequence_Fast_GET_ITEM(seq, ii);
#if PY_MAJOR_VERSION < 3
		if (PyInt_Check(val)) {
			buf[ii] = (__u8)PyInt_AS_LONG(val);
		} else
#endif
		{
			if (PyLong_Check(val)) {
				buf[ii] = (__u8)PyLong_AS_LONG(val);
			} else {
				snprintf(wrmsg_text, sizeof (wrmsg_text) - 1, wrmsg_val, val);
				PyErr_SetString(PyExc_TypeError, wrmsg_text);
				return NULL;
			}
		}
	}

	Py_DECREF(seq);

	status = write(self->fd, &buf[0], len);

	if (status < 0) {
		PyErr_SetFromErrno(PyExc_IOError);
		return NULL;
	}

	if (status != len) {
		perror("short write");
		return NULL;
	}

	Py_INCREF(Py_None);
	return Py_None;
}

PyDoc_STRVAR(SpiDev_read_doc,
	"read(len) -> [values]\n\n"
	"Read len bytes from SPI device.\n");

static PyObject *
SpiDev_readbytes(SpiDevObject *self, PyObject *args)
{
	uint8_t	rxbuf[SPIDEV_MAXPATH];
	int		status, len, ii;
	PyObject	*list;

	if (!PyArg_ParseTuple(args, "i:read", &len))
		return NULL;

	/* read at least 1 byte, no more than SPIDEV_MAXPATH */
	if (len < 1)
		len = 1;
	else if ((unsigned)len > sizeof(rxbuf))
		len = sizeof(rxbuf);

	memset(rxbuf, 0, sizeof rxbuf);
	status = read(self->fd, &rxbuf[0], len);

	if (status < 0) {
		PyErr_SetFromErrno(PyExc_IOError);
		return NULL;
	}

	if (status != len) {
		perror("short read");
		return NULL;
	}

	list = PyList_New(len);

	for (ii = 0; ii < len; ii++) {
		PyObject *val = Py_BuildValue("l", (long)rxbuf[ii]);
		PyList_SET_ITEM(list, ii, val);
	}

	return list;
}

PyDoc_STRVAR(SpiDev_xfer_doc,
	"xfer([values]) -> [values]\n\n"
	"Perform SPI transaction.\n"
	"CS will be released and reactivated between blocks.\n"
	"delay specifies delay in usec between blocks.\n");

static PyObject *
SpiDev_xfer(SpiDevObject *self, PyObject *args)
{
	uint16_t ii, len;
	int status;
	uint16_t delay_usecs = 0;
	uint32_t speed_hz = 0;
	uint8_t bits_per_word = 0;
	PyObject *obj;
	PyObject *seq;
#ifdef SPIDEV_SINGLE
	struct spi_ioc_transfer *xferptr;
	memset(&xferptr, 0, sizeof(xferptr));
#else
	struct spi_ioc_transfer xfer;
	memset(&xfer, 0, sizeof(xfer));
#endif
	uint8_t *txbuf, *rxbuf;
	char	wrmsg_text[4096];

	if (!PyArg_ParseTuple(args, "O|IHB:xfer", &obj, &speed_hz, &delay_usecs, &bits_per_word))
		return NULL;

	seq = PySequence_Fast(obj, "expected a sequence");
	len = PySequence_Fast_GET_SIZE(seq);
	if (!seq || len <= 0) {
		PyErr_SetString(PyExc_TypeError, wrmsg_list0);
		return NULL;
	}

	if (len > SPIDEV_MAXPATH) {
		snprintf(wrmsg_text, sizeof(wrmsg_text) - 1, wrmsg_listmax, SPIDEV_MAXPATH);
		PyErr_SetString(PyExc_OverflowError, wrmsg_text);
		return NULL;
	}

	txbuf = malloc(sizeof(__u8) * len);
	rxbuf = malloc(sizeof(__u8) * len);
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

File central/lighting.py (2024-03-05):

import time
from rpi_ws281x import *
import argparse
import global_vars
 
LED_COUNT      = 88    
LED_PIN        = 18      
LED_FREQ_HZ    = 800000  # LED signal frequency in hertz (usually 800khz)
LED_DMA        = 10      # DMA channel to use for generating a signal (try 10)
LED_BRIGHTNESS = (int)(255*0.2)     # Set to 0 for darkest and 255 for brightest
LED_INVERT     = True   # True to invert the signal (when using NrasPN transistor level shift)
LED_CHANNEL    = 0       # set to '1' for GPIOs 13, 19, 41, 45 or 53
 
 
# Hard-coded the indexes of each light on the panel based on our "snake" solder pattern
LEFT_LEDS_TOP = [0, 1, 2, 3, 4, 5, 6, 7, 8, 9, 10, 33, 34, 35, 36, 37, 38, 39, 40, 41, 42, 43]
LEFT_LEDS_BOT = [44, 45, 46, 47, 48, 49, 50, 51, 52, 53, 54, 77, 78, 79, 80, 81, 82, 83, 84, 85, 86, 87]
RIGHT_LEDS_TOP = [11, 12, 13, 14, 15, 16, 17, 18, 19, 20, 21, 22, 23, 24, 25, 26, 27, 28, 29, 30, 31, 32]
RIGHT_LEDS_BOT = [55, 56, 57, 58, 59, 60, 61, 62, 63, 64, 65, 66, 67, 68, 69, 70, 71, 72, 73, 74, 75, 76]
 
# ARROW_LEFT = [43, 44, 3, 84, 2, 85, 33, 34, 35, 36, 37, 38, 39, 40, 41, 42, 45, 46, 47, 48, 49, 50, 51, 52, 53, 54]
ARROW_RIGHT = [54, 33, 53, 34, 52, 35, 51, 36, 50, 37, 49, 38, 48, 39, 47, 40, 85, 46, 41, 2, 45, 42, 44, 43, 86, 1]

# ARROW_RIGHT = [22, 65, 23, 64, 18, 19, 68, 69, 24, 25, 26, 27, 28, 29, 30, 31, 32, 55, 56, 57, 58, 59, 60, 61, 62, 63]
ARROW_LEFT = [55, 32, 56, 31, 57, 30, 58, 29, 59, 28, 60, 27, 61, 26, 62, 25, 68, 63, 24, 19, 64, 23, 65, 22, 67, 20]

BRAKE = list(range(0, LED_COUNT))

f = [67,64,23,20, 68, 24, 69, 25, 71, 60, 27, 16, 15, 73, 58, 29, 14, 75, 76, 77, 56, 31, 12, 11,10, 79, 52, 35, 8, 51, 36, 81, 6, 84, 47, 40, 3, 2,1, 86, 45, 42]

strip = Adafruit_NeoPixel(LED_COUNT, LED_PIN, LED_FREQ_HZ, LED_DMA, LED_INVERT, LED_BRIGHTNESS, LED_CHANNEL)
# Intialize the library (must be called once before other functions).

# Light the whole panel red
def brake_lights_on():
    for i in BRAKE[66:]:
        strip.setPixelColor(i, Color(255, 0, 0, 0))
    strip.show()
    time.sleep(0.05)
    
    for i in BRAKE[44:66]:
        strip.setPixelColor(i, Color(255, 0, 0, 0))
    strip.show()
    time.sleep(0.05)

    for i in BRAKE[22:44]:
        strip.setPixelColor(i, Color(255, 0, 0, 0))
    strip.show()
    time.sleep(0.05)

    for i in BRAKE[0:22]:
        strip.setPixelColor(i, Color(255, 0, 0, 0))
    strip.show()

def flip_off():
    lights_off()
    time.sleep(1)
    for i in f:
        strip.setPixelColor(i, Color(255, 0, 0, 0))
    strip.show()
    time.sleep(1)
 
# Turn of all the lights
def lights_off():
    for i in range(LED_COUNT):
        strip.setPixelColor(i, Color(0, 0, 0, 0))
    strip.show()

def idle_color():
    for i in range(LED_COUNT):
        strip.setPixelColor(i, Color(255, 75, 0, 0))
    strip.show()
 
# Light the right or left side of the panel red (arrow), backdrop yellow
def signal_on(direction):
    arrow = ARROW_LEFT
 
    if direction == "RIGHT":
        arrow = ARROW_RIGHT
 
    idle_color()
    
    time.sleep(0.5)
 
    for i in arrow[:6]:
        strip.setPixelColor(i, Color(255, 0, 0, 0))
    time.sleep(0.1)
    strip.show()

    for i in arrow[6:12]:
        strip.setPixelColor(i, Color(255, 0, 0, 0))
    time.sleep(0.1)
    strip.show()

    for i in arrow[12:18]:
        strip.setPixelColor(i, Color(255, 0, 0, 0))
    time.sleep(0.1)
    strip.show()

    for i in arrow[18:]:
        strip.setPixelColor(i, Color(255, 0, 0, 0))
    time.sleep(0.1)
    strip.show()
    time.sleep(0.5)
 
    
def update_lights():
    strip.begin()

    while not global_vars.kill_light_thread.is_set():
        if(global_vars.brake == 1):
            brake_lights_on()
            # flip_off()
            print("Braking")
        elif(global_vars.turn == 1):
            signal_on("LEFT")
            print("Turning Left")
        elif(global_vars.turn == -1):
            signal_on("RIGHT")
            print("Turning Right")
        else:
            idle_color()
        
    lights_off()
    print("Lights Killed")
            

# # Main program logic follows:
# #This section won't be running during the thread
if __name__ == '__main__':

    try:
        global_vars.turn = -1 #Allows you to test the code 
        update_lights()
 
    except KeyboardInterrupt:
        lights_off()

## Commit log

2023-07-04 Added Interrupts for Switches
2023-07-05 Importing RF24 Library, however, will be changing to arduino comm approach
2023-07-05 Multithreading of lighting added Wireless Turn Signal Works
2023-07-05 Haptic Side Code can transmit the status of turn button to Raspberry Pi Wirelessly
2023-07-07 Code reoganized into modules and thread -Haptic Code added
2023-07-07 Haptic Code added to Arduino -Code structured and organized
2023-07-09 Central 3D Bodies
    [left_back_plate.stl, left_body.stl, left_front_plate.stl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]
2023-07-10 Accelerometer braking detection integrated in threading
2023-07-10 Added Skeleton for distance thread
2023-07-16 Cleaned up Folders
    [left_back_plate.stl, left_body.stl, left_front_plate.stl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]
2023-07-24 Fixed Comm Frequency and size
    [comm.py]
2023-07-24 guest wireless change
2023-07-25 Fixed Motors randomly vibrating
2023-07-25 Braking Flickering Fixed Comm Verbose suppressed Accel Verbose Enabled
    [accel.py, comm.py]
2023-07-26 fix brake detection
2023-07-26 new calibration
2023-07-26 Fixed Startup on boot
    [accel.py, main.py]
2023-08-21 Added Code to work with Lidar Distance Detection
2024-01-20 Added new 3D models and PCB file
    [Central Controller.scad, Central-base.step, Central-lid.step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]
2024-01-23 Added files ready to print and cut
    [Acrylic Cover.dxf, Central-base v3.stl, Central-lid v5.f3d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]
2024-01-29 Updated lidar dist detection to avoid mistriggers
    [lidar_dist.py, lighting.py]
2024-01-29 modified arduino haptic to avoid motor on after out of range
2024-01-29 new lidar loop
2024-01-29 added lidar code with counter
2024-01-31 Added Low Pass filtering config to MPU6050 for better Brake detection
2024-02-13 Updated latest PCB files
2024-02-13 Added LED Blinking code for left/right turn signal
2024-02-13 Added Pin mode
2024-02-14 Added mode switch and indicator
2024-02-29 Added Distance modes and prevent ghosting
    [comm.py, lidar_dist.py, main.py]
2024-03-03 Fixed light priority and lidar fix
    [lidar_dist.py, lighting.py]
2024-03-04 Added Poster and PCB Scan
2024-03-05 Lidar calibrated for Outdoor
2024-03-11 Added Mounting 3D File

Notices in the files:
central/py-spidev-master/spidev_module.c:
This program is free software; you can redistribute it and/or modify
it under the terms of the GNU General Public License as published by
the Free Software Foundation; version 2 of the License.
